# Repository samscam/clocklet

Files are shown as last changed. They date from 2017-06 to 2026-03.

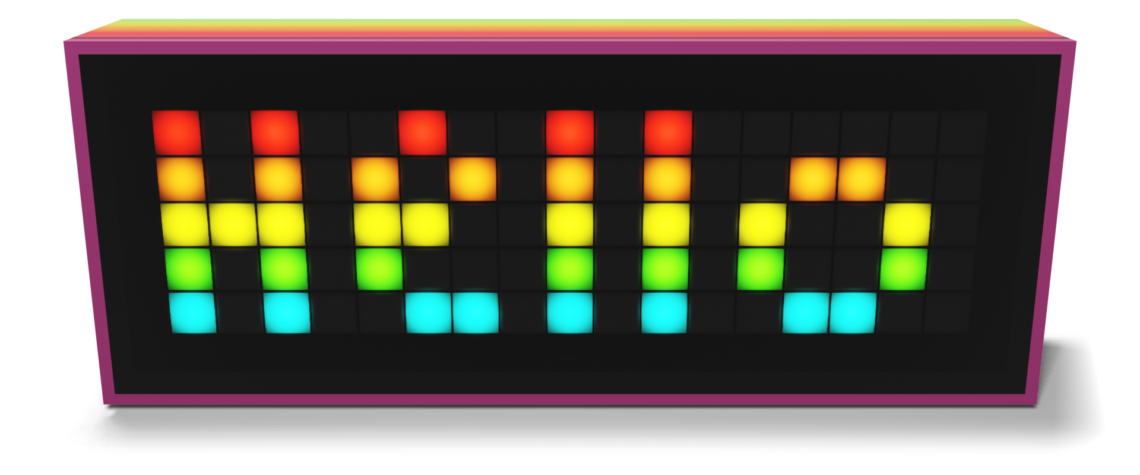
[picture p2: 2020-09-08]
Website/images/clocklet5-tequillasunrise.png

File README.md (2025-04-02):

# Clocklet

See also [clocklet.co.uk](https://clocklet.co.uk)

## Overview

This project is the firmware and client apps for clocks made by @samscam including:

### Clocklet
* Custom 17x5 SK9822 LED Matrix display
* Timekeeping: ESP32 (DS3231 as backup)
* Synchronisation: NTP
* Microcontroller: ESP32 Wrover on custom "Clockbrain" board
* Weather source: OpenWeatherMap

### Old Clocklet / Clocky
Earlier prototypes used RGBDigit (WS2812B) 7-segment display and Adafruit Feather Huzzah32.

### Mrs Clockety
* Display: Waveshare epaper 2.9inch https://www.waveshare.com/2.9inch-e-paper-module.htm
* Timekeeping: GPS
* Synchronisation: GPS
* Power management to run from a lipo battery
* Microcontroller: Adafruit Feather Huzzah32

It's all a work in progress.

## Main Features

* Time
* Weather
* Utterances
* Interesing displays and animation
* Ambient light sensing
* Power management (Mrs Clockety)

## Firmware

To build the the firmware:

* Clone the repo **including submodules**
* Install platformio and your editor of choice - I'm using vscode.
* Open up the firmware from the `Embedded` directory
* Pick the *correct environment* for the device you want to build for (by setting it in the first line of `platformio.ini` or by invoking tasks for the specific environment in the editor/cli) this will probably be `clockbrain`
* Plug the device in to your machine over USB
* Check that the device is available to your system... on MacOS it's normally `/dev/cu.SLAB_USBtoUART`
* Build and upload (platformio should download the dependencies if it hasn't done so already)
* Note that API keys are encrypted with gitcrypt

## Seeing the logs (without installing anything much)

You can connect to the clocklet's serial port from a computer with various tools (like screen, miniterm or putty) and see the Clocklet logging.

The important thing to note is that the baud rate of the serial connection is `115200`.

The Clocklet serial port on Mac and Linux will be available as something like `/dev/cu.SLAB_USBtoUART` - you can do an `ls /dev/cu.*` before and after plugging it in to eliminate possibilities.

Then open it up in your tool of choice:
`screen /dev/cu.SLAB_USBtoUART 115200`
`miniterm.py /dev/cu.SLAB_USBtoUART 115200`

## Manually updating firmware (with minimal installing)

1) Install `esptool`

On MacOS this can be done with homebrew: `brew install esptool`
On Linuxes it's probably available from `apt install esptool` or whatever package manager you're using.

2) Download the bin file of the firmware image you want from the releases section on here.

3) Plug in the Clocklet and figure out which port it is on - probably something like `/dev/cu.SLAB_USBtoUART` (that's what we'll use here but replace with whatever it is on your system)

4) Erase the flash (including settings)
`esptool.py -b 115200 -p /dev/cu.SLAB_USBtoUART erase_region 0x9000 0xFF7000`

5) Flash the new firmware image:

`esptool.py -b 115200 -p /dev/cu.SLAB_USBtoUART write_flash 0x10000 clockbrain.bin`

While we are here you can also use esptool to just erase settings (equivalent of doing a factory reset from the app): 
`esptool.py -b 115200 -p /dev/cu.SLAB_USBtoUART erase_region 0x9000 0x5000`

## Client App (iOS)

*Requires Xcode 16*
To build, open via the workspace rather than the Xcode Project.

Contains an experimental library for gluing CoreBluetooth to Combine and SwiftUI via PropertyWrappers called "CombineBluetooth". This may get spun out into a separate project in the future - but for ease of development right now it's in here.

## To follow

* Android client
* Enclosure design (3d printable)
* Hardware design

## License

This is distributed under the MIT License

    MIT License

    Copyright (c) 2017-2020 Sam Easterby-Smith

    Permission is hereby granted, free of charge, to any person obtaining a copy
    of this software and associated documentation files (the "Software"), to deal
    in the Software without restriction, including without limitation the rights
    to use, copy, modify, merge, publish, distribute, sublicense, and/or sell
    copies of the Software, and to permit persons to whom the Software is
    furnished to do so, subject to the following conditions:

    The above copyright notice and this permission notice shall be included in all
    copies or substantial portions of the Software.

    THE SOFTWARE IS PROVIDED "AS IS", WITHOUT WARRANTY OF ANY KIND, EXPRESS OR
    IMPLIED, INCLUDING BUT NOT LIMITED TO THE WARRANTIES OF MERCHANTABILITY,
    FITNESS FOR A PARTICULAR PURPOSE AND NONINFRINGEMENT. IN NO EVENT SHALL THE
    AUTHORS OR COPYRIGHT HOLDERS BE LIABLE FOR ANY CLAIM, DAMAGES OR OTHER
    LIABILITY, WHETHER IN AN ACTION OF CONTRACT, TORT OR OTHERWISE, ARISING FROM,
    OUT OF OR IN CONNECTION WITH THE SOFTWARE OR THE USE OR OTHER DEALINGS IN THE
    SOFTWARE.

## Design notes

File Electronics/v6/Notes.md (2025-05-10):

# V6 design notes

## USB-C Socket

On the v5 I had a sticky-out socket (in the middle of the board)
For this one do we want to carry on with that, and have it exit at the rear, (standing paste) or come out at the side (horizontal attach, which would be simpler??)

There are bazillions in the JLC catalogue but we are talking
- 16 pin
- good enough rating for current (need to work out hypothetical max limit)

## ESD protection

Doing this right is more complex than I had thought.

We need over-voltage protection and ESD protection.
on Vbus
CC lines
D+/- lines

Options: 

### The semtech way:
https://www.semtech.com/uploads/design-support/TVS_App_Notes-SI21-03-ESD_Protection_of_USB_Type-C_Interfaces.pdf

Semtech TDS2221PW for vBUS
µClamp2411ZA for CC
RClamp4021ZA for D+/-

Or they do this thing
https://estore.st.com/en/tcpp01-m12-cpn.html

### The TI way:
https://www.ti.com/lit/ta/ssztal6/ssztal6.pdf

TPD6S300
does 6 channels CC, SBU, D+/-
or TPD8S300 for 8 channels
Still need something for vbus
https://www.ti.com/lit/ds/slvsdk3c/slvsdk3c.pdf?ts=1744796360041

TPD4S480
4 channels, newer, 48v compliant
https://www.ti.com/lit/ds/symlink/tpd4s480.pdf

ESD122 - if we wanted to do the high speed lines (but we don't)
https://www.ti.com/lit/ds/symlink/esd122.pdf

## USB-PD controller

TPS25730
https://www.ti.com/lit/ds/symlink/tps25730.pdf

Has a 3v3 LDO built in for output BUT that's limited to 0.1A

TPS25751 has built in esd protection... and moisure detection
https://www.ti.com/lit/ds/symlink/tps25751.pdf

TPS26750 doesn't have esd - says you should pair with TPD4S480
https://www.ti.com/product/TPS26750

## LDO

These both coming off the PPHV line of the PD controller...

3.3v
then we need an LDO for the 3v3 supply for the MCU
old one was AP2112K-3.3
JLC have AMS1117 (which is rated for 1A)

5v
Presuming that we are sticking with 5v LEDs...

Possibly a buck?

Or is there a dual channel power regulator thing? One for 5v and one for 3.3v?

## MUX

It's probably unnecessary but we could put a mux on the D+- lines. Or just join them together.

## MCU

Espressiv ESP32-S3
https://www.espressif.com/sites/default/files/documentation/esp32-s3_datasheet_en.pdf

Sensible plan is to use the "mini" one with built-in antenna.
Which does have placement implications.
It's that or go there with doing RF and have an antenna somewhere.
Current rating recommendation 500mA.

## LEDs

current - 5*17 matrix = 85 LEDs

Currently using SK9822
http://www.normandled.com/upload/201909/SK9822%20LED%20Datasheet.pdf
Those are max 20ma each = 1.7A

Which puts our total max power budget at roughly 2.4A * 5V = 12W
(but we never actually go that high, probably)

As we are getting PCBA this time... Possibly do 2020 ones?

2020s seem to work out more like 18ma

HD107
HD108 - 16bit - 20ma in the 5050 package
https://www.rose-lighting.com/wp-content/uploads/sites/53/2019/11/HD108-led.pdf
(rose lighting datasheets are a mess)

WS2816 (recently supported in fastled) - is a 1-wire thing but 16-bit.
Better availability... but not sure I like it and would prefer the APA102 style spi interface.
SK9822 are readily available.

BIG QUESTION:
Single board with everything on one side.
Double sided.
Sandwich

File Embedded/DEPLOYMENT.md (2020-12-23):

# Clocklet deployment procedure

1) Plug in, then insert battery
2) Burn efuses (including serial number)
3) Apply profile to CP2012N (with Simplicity Studio)
4) Flash the firmware
5) Get the time set in the DS3231
6) Erase to defaults

## Clockbrain efuse map

EFUSE block 3:
0        1        2        3        4        5        6        7        << words
0        4        8        12       16       20       24       28       << bytes
0        32       64       96       128      160      192      224      << bits
00000000 00000000 00000000 00000000 00000000 00000000 00000000 00000000 << hex
reserved xxxx                                         ^ hw     ^ serial

So that's block 6 for the hardware revision (uint16) and case colour (uint16)
And block 7 for the serial number (uint32)

## Writing the efuse

Adjust the serial number in the `efuse.bin` file - remember it's LITTLE ENDIAN.

hwrev    serial
V        V
05000300 08000000
    ^
    case colour

And burn it!

~/.platformio/packages/tool-esptoolpy/espefuse.py --port /dev/tty.usbserial-114440 burn_block_data --offset 24 BLK3 efuse.bin

(use --force-write-always if necessary)

Case colours
00 (unset) raw hardware
01 fake wood
02 translucent
03 rainbow blue-pink
04 white
05 galaxy black
06 gold
07 tequilla sunrise

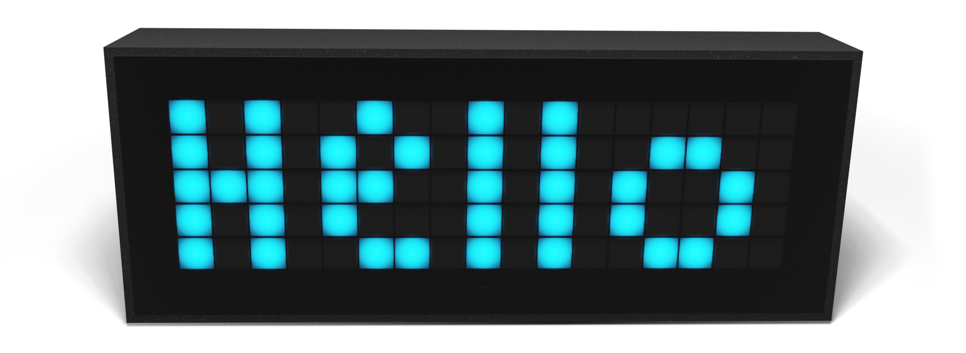
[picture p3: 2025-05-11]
Website/images/clocklet5-blue-hello.png

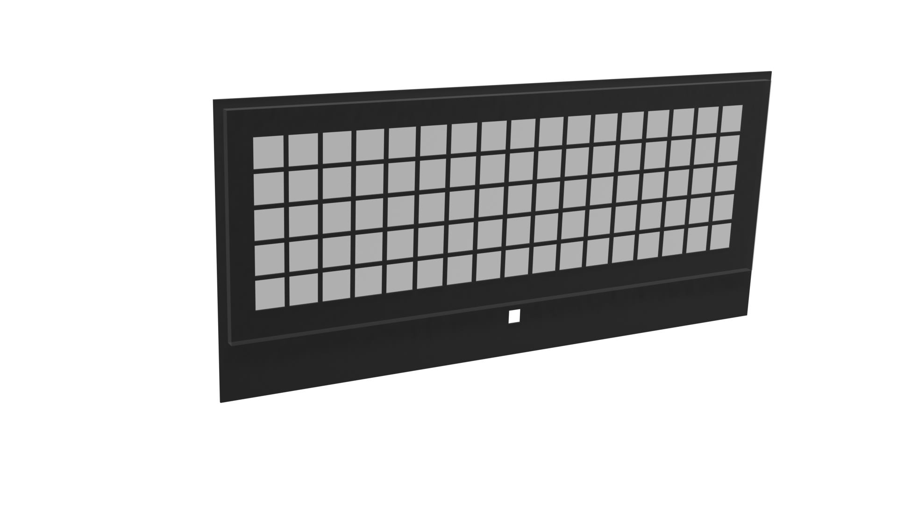
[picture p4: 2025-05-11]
Website/images/clocklet5-black-mask.png

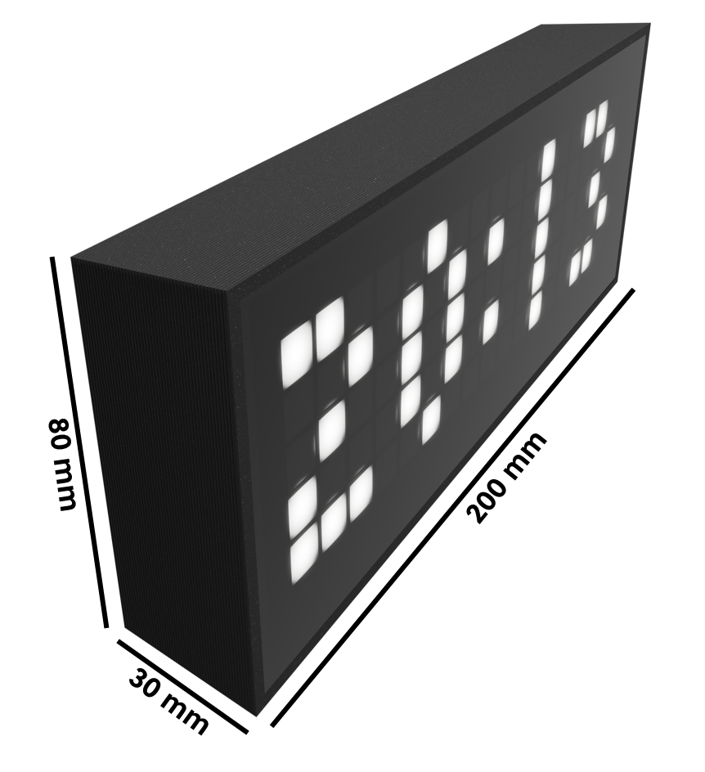
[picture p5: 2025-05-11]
Website/images/dimensions.png

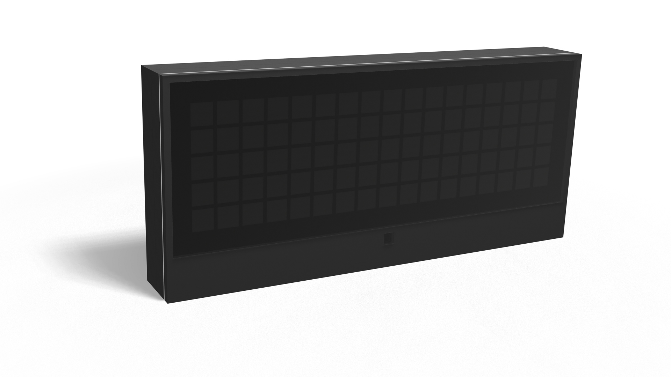
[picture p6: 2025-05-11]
Website/images/clocklet5-black-blank.png

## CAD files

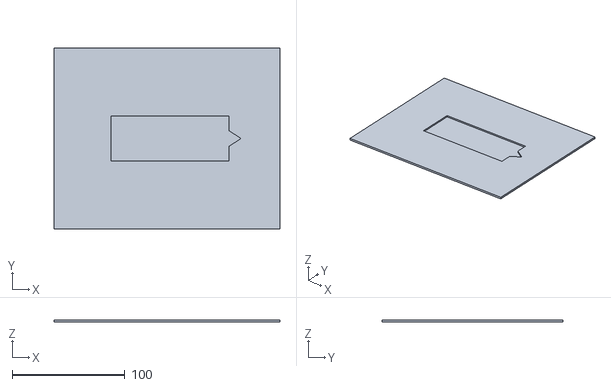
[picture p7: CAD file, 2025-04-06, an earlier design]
Electronics/v5/Display-2020/stencil holder.stl
200.0 x 160.0 x 2.00

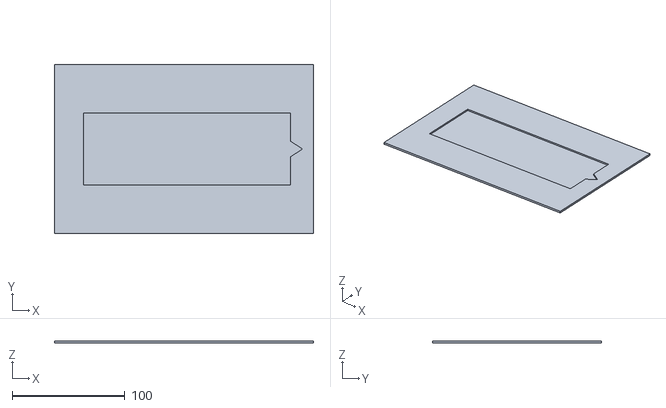
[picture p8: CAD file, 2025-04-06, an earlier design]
Electronics/v5/Display-APA/stencil holder.stl
230.0 x 150.0 x 2.00

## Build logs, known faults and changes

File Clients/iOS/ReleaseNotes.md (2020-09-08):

# Clocklet iOS Release notes

## v1.0 (92)

This goes with Clocklet firmware v1.0.1

### NEW USERS HELLO!

Plug in your clock, run the app, set up network and location. Happy clock!

### NEW STUFF IN THIS VERSION

* Changing locations
You can now change the location of the Clocklet on the new location settings screen. There are some canned examples or you can set it to your real location. Changing location will also trigger a weather update - though if you change locations repeatedly you will likely end up with the weather for a previous place.

* International time zone and DST support
The clock's time should reflect the time in the chosen location. Even for places with crazy timezones.

* Bluetooth status improvements
On your phone, if bluetooth is switched off or not authorised you should see a helpful overlay telling you to do something about it.
The app will now correctly report when pairing data is messed up - you can (if you really want to) test this by performing a factory reset on the clock and then trying to reconnect. To clear the error, remove the clocklet from your phone's bluetooth settings and try connecting again. No need to kill the app.

* Various layout improvements in the app
* Fixed occasional jerkyness on the Clocklet's display (by running network tasks on the other core)

### MIGRATIONS FROM EARLIER VERSIONS

After installing the app, check your Clocklet's firmware version is v1.0.1 in the technical stuff section. Rebooting will trigger an update if it hasn't already done it.

Background or quit the app while the clock is doing the firmware update - otherwise the update will fail.

After performing a firmware update, or otherwise if settings are missing/messed up in the app, you should switch bluetooth on your phone off and on again to clear the bluetooth cache.

After migrating, your phone will report the Clock's location as "Nowhere" - just change the location to sort it out.

### ANNOYING BUGS

I've had a few times where the Clocklet fails to advertise itself properly, thus either not showing up in the app or looking like a circuit board. Turning the clock off and on again should fix it.

Have seen some occasional crashes on the clocklet (shortly after startup or after multiple location changes) but they also seem to sort themselves out. Will carry on trying to track them down.

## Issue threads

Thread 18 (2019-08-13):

NTP goes into loop when starting with a fresh DS3231

samscam, 2019-08-13:
The daily updates fire continuously - presumably the initial time hasn't stuck.
Or something... It started working in the end. Investigate...

samscam, 2020-05-15:
This is all down to known behaviour with a fresh DS3231 - Apply power to 3v3 before inserting battery.

Closed 2020-05-15.

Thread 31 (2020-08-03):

Firmware Updates fail if also trying to do other network stuff (like scanning because bluetooth is connected)

samscam, 2020-08-03:

samscam, 2020-09-08:
This has been fixed by having switched over to Nimble. Closing.

Closed 2020-09-08.

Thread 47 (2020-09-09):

iOS start Bluetooth search AFTER Bluetooth perm has been granted

samscam, 2020-09-09:
When you give bluetooth permission on the first run it has already tried to scan, and has probably failed. Users need to manually tap the scan button. Not good enough!

Closed 2022-12-30.

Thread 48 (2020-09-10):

Bob's network joining problems

samscam, 2020-09-10:
Bob is struggling to get it to connect to his network.

Possible causes:
Watchdog timer - likely network scan task stuck in a loop
Mutex locks relating to system time - main clock process vs nimble
WEP
Network characteristic over-subscribing to network events

samscam, 2020-09-12:
Another possible cause might be hidden SSIDs

samscam, 2020-09-12:
We can safely discount WEP. Did a bunch of tests on it and it was fine.

samscam, 2022-12-09:
Closing this as I presume it's fine now.

Closed 2022-12-09.

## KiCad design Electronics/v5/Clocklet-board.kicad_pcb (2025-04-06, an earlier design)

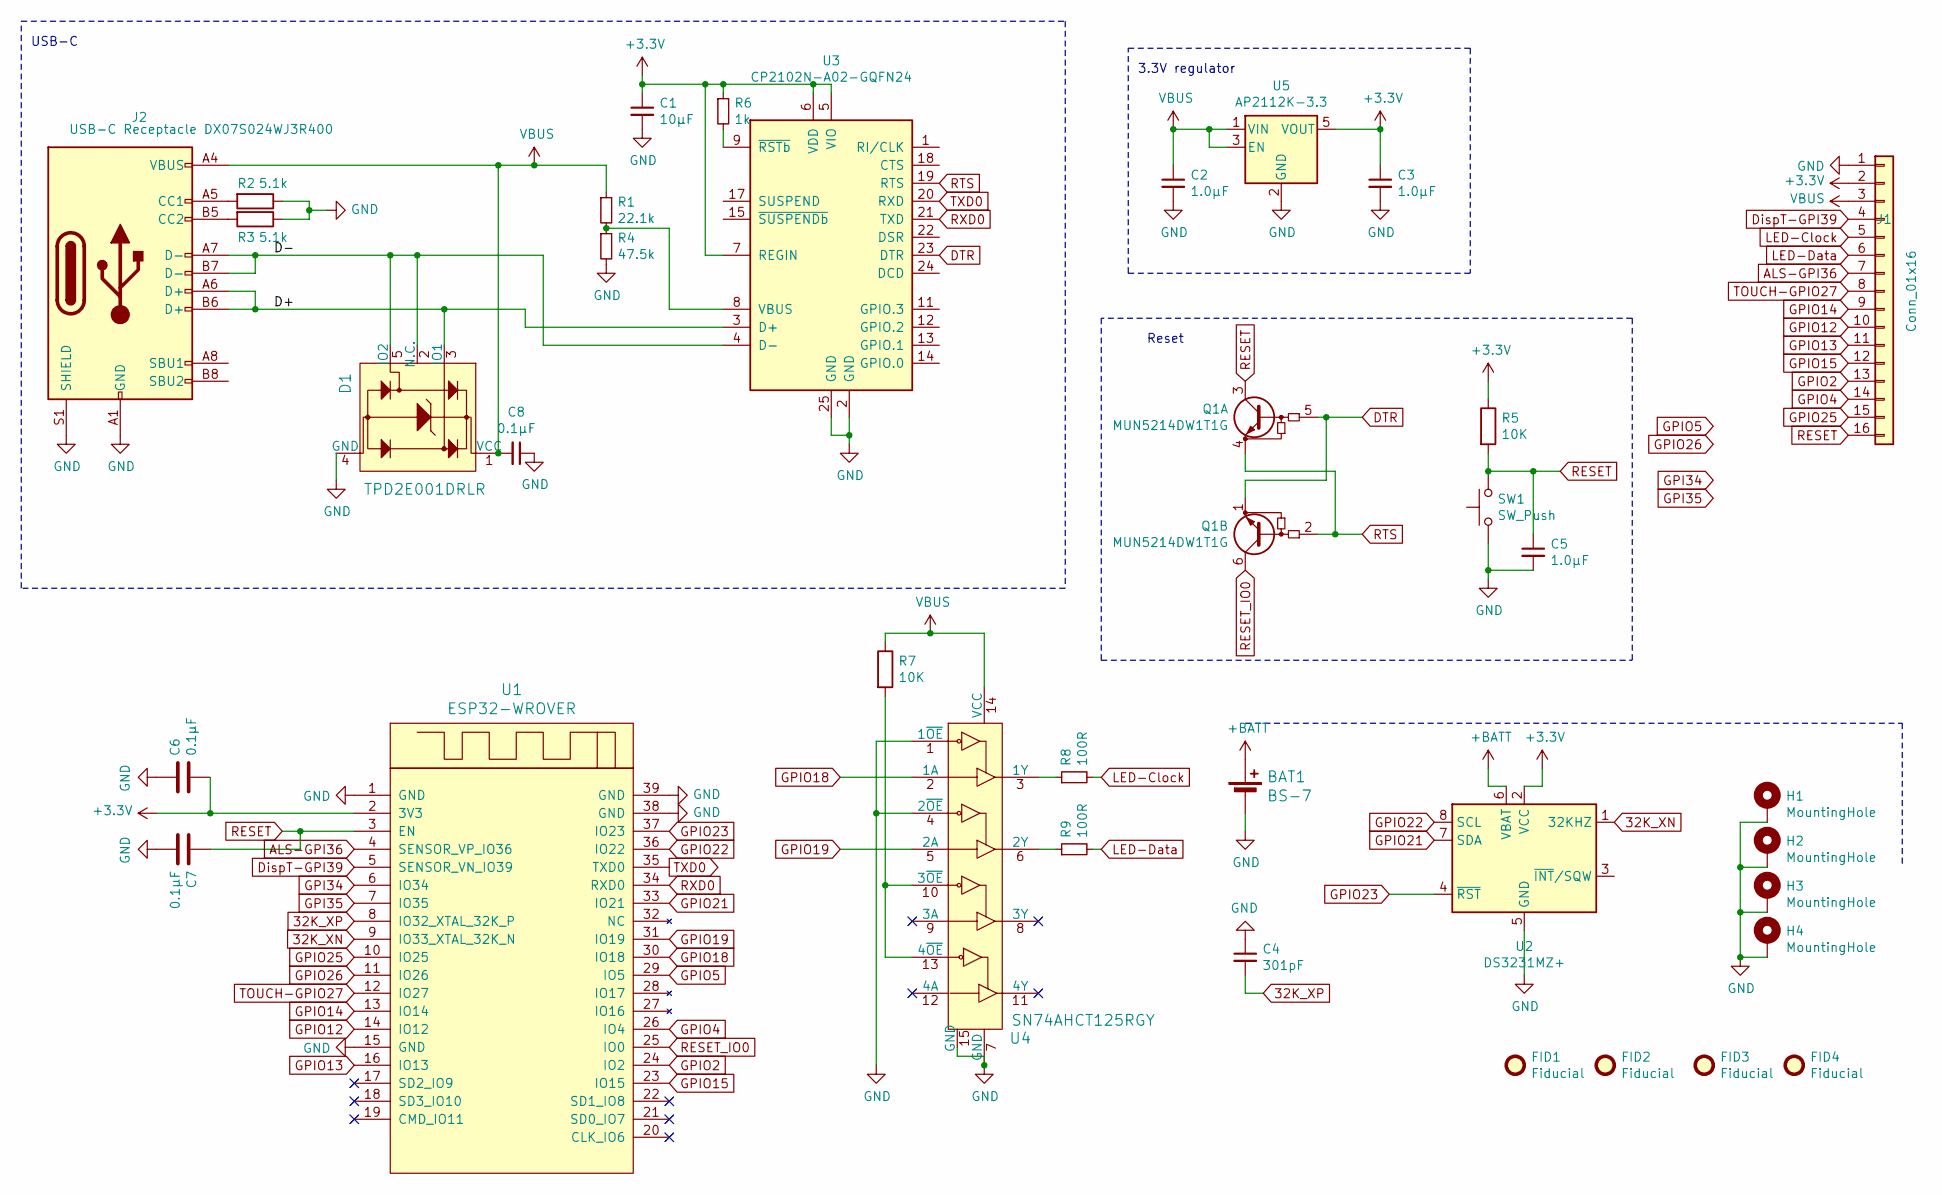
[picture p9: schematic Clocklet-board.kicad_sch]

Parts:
BAT1: BS-7; BatteryHolder_Keystone_3000_1x12mm; MPN BS-7; Digi-Key_PN BS-7-ND
C1: 10µF; C_0603_1608Metric; Mouser Ref 80-C0603C106M8PACTU
C2, C3, C5: 1.0µF; C_0603_1608Metric; Mouser Ref 80-C0603C105K4PLR
C4: 301pF; C_0603_1608Metric; Mouser Ref 80-C0603C301J8HACTU
C6, C7, C8: 0.1µF; C_0603_1608Metric; Mouser Ref 710-885012206071
D1: TPD2E001DRLR; SOT-553; MPN TPD2E001DRLR; Digi-Key_PN 296-21883-1-ND
FID1, FID2, FID3, FID4: Fiducial; Fiducial_0.5mm_Mask1mm
H1: MountingHole; MountingHole_2.7mm_M2.5_Pad_Via
H2, H3, H4: MountingHole; MountingHole_2.5mm_Pad_Via
J1: Conn_01x16; PinHeader_1x16_P2.54mm_Vertical
J2: USB-C Receptacle DX07S024WJ3R400; USB-C_Female_Vert_DX07S024WJ3R400-Corrected; Mouser Ref 656-DX07S0024WJ3R400
Q1: MUN5214DW1T1G; SOT-363_SC-70-6; Mouser Ref 863-MUN5214DW1T1G
R1: 22.1k; R_0603_1608Metric; Mouser Ref 71-CRCW060322K1FKEAC
R2, R3: 5.1k; R_0603_1608Metric; Mouser Ref 71-CRCW06035K10FKEAC
R4: 47.5k; R_0603_1608Metric; Mouser Ref 71-CRCW060347K5FKEAC
R5, R7: 10K; R_0603_1608Metric; Mouser Ref 71-CRCW060310K0FKEAC
R6: 1k; R_0603_1608Metric; Mouser Ref 71-CRCW06031K00FKEAC
R8, R9: 100R; R_0603_1608Metric; Mouser Ref 71-CRCW0603100RFKEAC
SW1: SW_Push; SW_SPST_B3U-1000P; Mouser Ref 653-B3U-1000P
U1: ESP32-WROVER; ESP32-WROVER-B-Recs; Mouser Ref 356-ESP32-WROB(16MB)
U2: DS3231MZ+; SOIC-8_3.9x4.9mm_P1.27mm; Mouser Ref 700-DS3231MZ+
U3: CP2102N-A02-GQFN24; QFN-24-1EP_4x4mm_P0.5mm_EP2.6x2.6mm_ThermalVias; Mouser Ref 634-CP2102NA02GQFN24
U4: SN74AHCT125RGY; Texas_S-PVQFN-N14_ThermalVias; MPN SN74AHCT125N; Digi-Key_PN 296-4655-5-ND
U5: AP2112K-3.3; SOT-23-5; Mouser Ref 621-AP2112K-3.3TRG1

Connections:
32K_XN: U1.9 (IO33_XTAL_32K_N), U2.1 (32KHZ)
32K_XP: C4.2, U1.8 (IO32_XTAL_32K_P)
+3V3: C1.1, C3.1, C6.2, J1.2, R5.1, R6.1, U1.2 (3V3), U2.2 (VCC), U3.5 (VIO), U3.6 (VDD), U3.7 (REGIN), U5.5 (VOUT)
+BATT: BAT1.1 (+), U2.6 (VBAT)
/D+: D1.3 (IO1), J2.A6 (D+), J2.B6 (D+), U3.3 (D+)
/D-: D1.2 (N.C.), D1.5 (IO2), J2.A7 (D-), J2.B7 (D-), U3.4 (D-)
ALS-GPI36: J1.7, U1.4 (SENSOR_VP_IO36)
DTR: Q1.1 (E1), Q1.5 (B1), U3.23 (DTR)
DispT-GPI39: J1.4, U1.5 (SENSOR_VN_IO39)
GND: BAT1.2 (-), C1.2, C2.2, C3.2, C4.1, C5.2, C6.1, C7.2, C8.1, D1.4 (GND), H1.1, H2.1, H3.1, H4.1, J1.1, J2.A1 (GND), J2.A12 (GND), J2.B1 (GND), J2.B12 (GND), J2.S1 (SHIELD), R2.1, R3.1, R4.2, SW1.1, U1.1 (GND), U1.15 (GND), U1.38 (GND), U1.39 (GND), U2.5 (GND), U3.2 (GND), U3.25 (GND), U4.1 (1~OE), U4.4 (2~OE), U4.7 (GND), U4.15 (GND), U5.2 (GND)
GPI34: U1.6 (IO34)
GPI35: U1.7 (IO35)
GPIO2: J1.13, U1.24 (IO2)
GPIO4: J1.14, U1.26 (IO4)
GPIO5: U1.29 (IO5)
GPIO12: J1.10, U1.14 (IO12)
GPIO13: J1.11, U1.16 (IO13)
GPIO14: J1.9, U1.13 (IO14)
GPIO15: J1.12, U1.23 (IO15)
GPIO18: U1.30 (IO18), U4.2 (1A)
GPIO19: U1.31 (IO19), U4.5 (2A)
GPIO21: U1.33 (IO21), U2.7 (SDA)
GPIO22: U1.36 (IO22), U2.8 (SCL)
GPIO23: U1.37 (IO23), U2.4 (~RST)
GPIO25: J1.15, U1.10 (IO25)
GPIO26: U1.11 (IO26)
LED-Clock: J1.5, R8.2
LED-Data: J1.6, R9.2
unnamed: J2.A5 (CC1), R2.2
unnamed: J2.B5 (CC2), R3.2
unnamed: R1.2, R4.1, U3.8 (VBUS)
unnamed: R6.2, U3.9 (~RSTb)
unnamed: R7.2, U4.10 (3~OE), U4.13 (4~OE)
unnamed: R8.1, U4.3 (1Y)
unnamed: R9.1, U4.6 (2Y)
RESET: C5.1, C7.1, J1.16, Q1.3 (C1), R5.2, SW1.2, U1.3 (EN)
RESET_IO0: Q1.6 (C1), U1.25 (IO0)
RTS: Q1.2 (B1), Q1.4 (E1), U3.19 (RTS)
RXD0: U1.34 (RXD0), U3.21 (TXD)
TOUCH-GPIO27: J1.8, U1.12 (IO27)
TXD0: U1.35 (TXD0), U3.20 (RXD)
VBUS: C2.1, C8.2, D1.1 (VCC), J1.3, J2.A4 (VBUS), J2.A9 (VBUS), J2.B4 (VBUS), J2.B9 (VBUS), R1.1, R7.1, U4.14 (VCC), U5.1 (VIN), U5.3 (EN)

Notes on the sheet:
3.3V regulator
Reset
USB-C

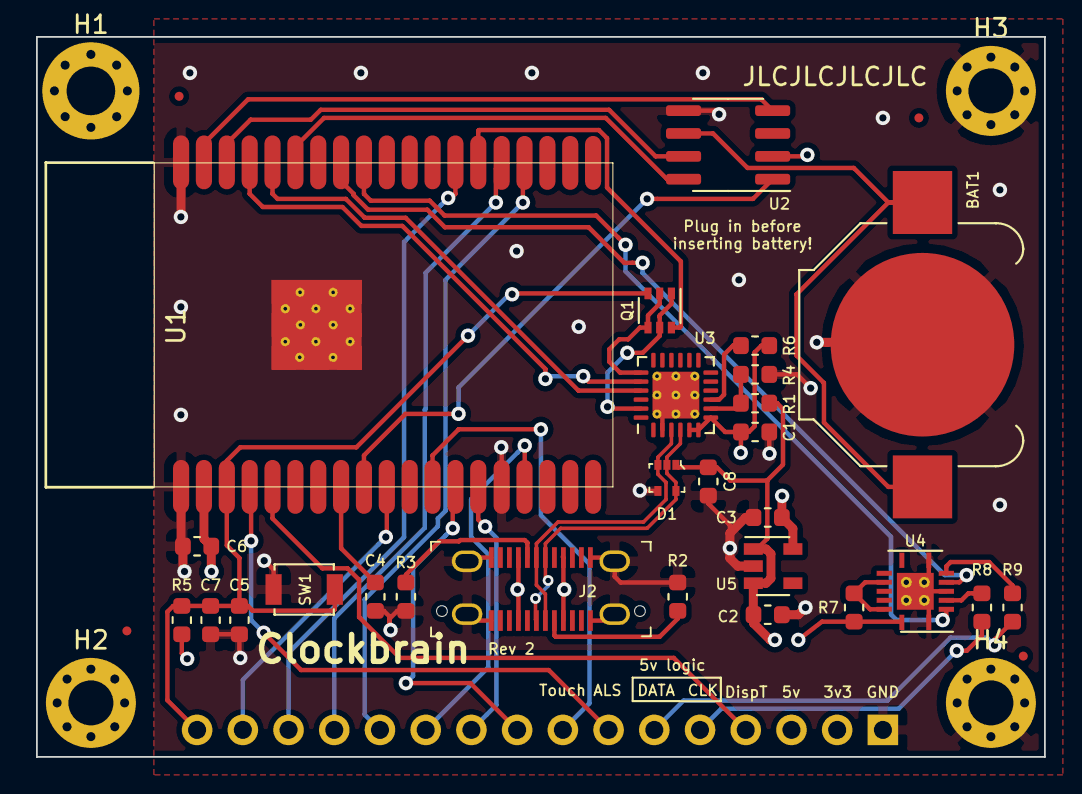
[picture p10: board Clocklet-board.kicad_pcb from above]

Board: 4 copper layers, 56.0 x 40.0 mm, 36 parts (1 on the bottom side), 38 nets.

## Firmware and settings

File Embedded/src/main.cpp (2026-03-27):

#include "main.h"

#include "Tests/Tests.h"
#include "settings.h"
#include "Messages.h"
#include "Displays/Display.h"
#include "Location/LocationSource.h"
#include "Location/LocationManager.h"
#include <WiFi.h>
#include <esp_log.h>

#include "Bluetooth/BlueStuff.h"

#include "FirmwareUpdates/FirmwareUpdates.h"
#include <Preferences.h>


#include "Loggery.h"

#include <rom/uart.h>
#include <soc/efuse_reg.h>

#include "TimeThings/TimeSync.h"

#include "ClockletSystem.h"

#define TAG "PRISCILLA"

// ----------- Display

#if defined(RAINBOWDISPLAY)

#include "Displays/RGBDigit.h"
RGBDigit display = RGBDigit();

#elif defined(MATRIX)

#include "Displays/Matrix/Matrix.h"
Matrix display = Matrix();

#elif defined(EPAPER)

#include "Displays/Epaper.h"
EpaperDisplay display = EpaperDisplay();

#endif


//Adafruit7 display = Adafruit7();

// #include "Displays/DebugDisplay.h"
// Display *display = new DebugDisplay();

// ----------- RTC

// We will always use the internal ESP32 time now...
#include "TimeThings/ESP32Rtc.h"
RTC_ESP32 rtc = RTC_ESP32();


#if defined(TIME_GPS)
#include "TimeThings/GPSTime.h"
RTC_GPS gpsRTC = RTC_GPS();
#endif

#if defined(TIME_DS3231)
RTC_DS3231 ds3231 = RTC_DS3231();
#endif

// TimeSync
TimeSync *timeSync;

// Location

#if defined(LOCATION_GPS)
LocationSource locationSource = rtc;
#else
LocationManager *locationManager;
#endif


// ---------- WEATHER CLIENT

// // #include "weather/met-office.h"
// // WeatherClient *weatherClient = new MetOffice(client); // << It's plain HTTP

// #include "weather/darksky.h"
// DarkSky weatherClient = DarkSky();

#include "weather/openweathermap.h"
OpenWeatherMap *weatherClient;

// RAINBOWS
#include "Weather/Rainbows.h"
Rainbows rainbows;

// Global Notification queues
QueueHandle_t bluetoothConnectedQueue;
QueueHandle_t prefsChangedQueue;
QueueHandle_t weatherChangedQueue;
QueueHandle_t locationChangedQueue;
QueueHandle_t networkChangedQueue;
QueueHandle_t networkStatusQueue;
QueueHandle_t firmwareUpdateQueue;
QueueHandle_t godModeQueue;

// God Mode
GodModeSettings godModeSettings;

// Firmware updater
FirmwareUpdates *firmwareUpdates;

// Update scheduler
UpdateScheduler updateScheduler = UpdateScheduler();

// Bluetooth implementation
BlueStuff *blueStuff;

// SETUP  --------------------------------------
void setup() {


  delay(2000);
  
  Serial.begin(115200);
  LOGMEM;
  // Say hello on Serial port
  Serial.println("");
  Serial.println("   ------------    ");
  Serial.println("  /            \\   ");
  Serial.println("  --------------   ");
  Serial.println(" |              |   ");
  Serial.println(" | ! CLOCKLET ! |   ");
  Serial.println(" |              |   ");
  Serial.println("  --------------   \n");

  Serial.printf("Firmware Version: %s (%s)\n",VERSION,GIT_HASH);

  // Read things from eFuse

  uint16_t hwrev = clocklet_hwrev();
  uint16_t caseColour = clocklet_caseColour();
  uint32_t serial = clocklet_serial();

  Serial.printf("Serial number: %d\n",serial);
  Serial.printf("Hardware revision: %d\n",hwrev);
  Serial.printf("Case Colour: %d\n",caseColour);

  // Read things from preferences...
  Preferences preferences = Preferences();
  preferences.begin("clocklet", false);

  // Post-update migrations
  String swmigrev = preferences.getString("swmigrev","0.0.0");

  if (swmigrev != VERSION){
    ESP_LOGI(TAG,"Previously running: %s\n",swmigrev.c_str());
    preferences.putString("swmigrev",VERSION);
    ESP_LOGI(TAG,"MIGRATED!");
  }

  preferences.end();

  LOGMEM;

  // Notification queues
  bluetoothConnectedQueue = xQueueCreate(1, sizeof(bool));
  prefsChangedQueue = xQueueCreate(1, sizeof(bool));
  weatherChangedQueue = xQueueCreate(1, sizeof(bool));
  locationChangedQueue = xQueueCreate(1, sizeof(bool));
  networkChangedQueue = xQueueCreate(1, sizeof(bool));
  networkStatusQueue =  xQueueCreate(1, sizeof(wl_status_t));
  firmwareUpdateQueue = xQueueCreate(1, sizeof(FirmwareUpdateStatus));
  godModeQueue = xQueueCreate(1, sizeof(GodModeSettings));

  // Analog input for light pin
  analogReadResolution(12);
  analogSetPinAttenuation(LIGHT_PIN,ADC_0db);

  // seed the brightness
  for (int i = 0; i<10 ; i++){
    currentBrightness();
    delay(100);
  }

  ESP_LOGI(TAG,"Clock starting!");


  display.setup();
  display.setBrightness(currentBrightness());


  // Uncomment to run various display tests:
  // displayTests(&display);  

  // DISPLAY A GREETING
  display.displayMessage("CLOCKLET",rainbow);

  updateDisplayPreferences();

  WiFi.begin();


  locationManager = new LocationManager(locationChangedQueue);
  ClockLocation currentLocation = locationManager->getLocation();

  blueStuff = new BlueStuff(bluetoothConnectedQueue,prefsChangedQueue,networkChangedQueue,networkStatusQueue,godModeQueue,locationManager);
  blueStuff->startBlueStuff();


  weatherClient = new OpenWeatherMap();
  weatherClient->weatherChangedQueue = weatherChangedQueue;
  weatherClient->setLocation(currentLocation);
  weatherClient->setTimeHorizon(12);
  updateScheduler.addJob(weatherClient,"weather",hourly);

  rainbows.setLocation(currentLocation);

  rtc.setTimeZone(currentLocation.timeZone);

  // Setup DS3231
  // Initialise I2c stuff (DS3231)
  #if defined(TIME_DS3231)

    #if defined(CLOCKBRAIN)
    Wire.begin(22, 21); // Got the damn pins the wrong way round on clockbrain
    #else
    Wire.begin();
    #endif

    if (!ds3231.begin()){
      ESP_LOGE(TAG,"Could not connect to DS3231");
    }

    timeSync = new TimeSync(&ds3231, &rtc); // << deliberately leaking these here - should really go smart pointers
    timeSync->performUpdate();
    updateScheduler.addJob(timeSync,"timesync",hourly);
    
  #endif




  // Start the internal RTC and NTP sync
  rtc.begin();

  // Firmware updatedr
  firmwareUpdates = new FirmwareUpdates(firmwareUpdateQueue);
  updateScheduler.addJob(firmwareUpdates,"firmware",daily);

  // Start Update Scheduler
  updateScheduler.start();

}

// LOOP  --------------------------------------


unsigned long lastRandomMessageTime = millis();
unsigned long nextMessageDelay = 1000 * 60 * 2;

unsigned long lastHourlyUpdate = 0;
unsigned long lastDailyUpdate = 0;


enum Precision {
  minutes, seconds, subseconds
};

Precision precision = subseconds;
// #if defined(RAINBOWDISPLAY)
// Precision precision = subseconds;
// #else
// Precision precision = minutes;
// #endif

bool didDisplay = false;

FirmwareUpdateStatus fwUpdateStatus = idle;
bool fwUpdateStarted = false;
bool bluetoothConnected = false;

float_t brightnessAdjust = 1;
bool autoBrightness = true;

void loop() {

  
  // ---- MONITOR QUEUES -----

  // ... preferences
  bool prefsDidChange = false;
  xQueueReceive(prefsChangedQueue, &prefsDidChange, (TickType_t)0 );
  if (prefsDidChange){
    ESP_LOGD(TAG,"PREFS DID CHANGE");
    updateDisplayPreferences();
  }
  
  display.setBrightness(currentBrightness());

  // ... weather
  bool weatherDidChange = false;
  xQueueReceive(weatherChangedQueue, &weatherDidChange, (TickType_t)0 );
  if (weatherDidChange && !godModeSettings.enabled){
    ESP_LOGI(TAG,"Weather did change");
    display.setWeather(weatherClient->horizonWeather);
    rainbows.setWeather(weatherClient->rainbowWeather);
  }

  // ... location
  bool locationDidChange = false;
  xQueueReceive(locationChangedQueue, &locationDidChange, (TickType_t)0 );
  if (locationDidChange){
    ESP_LOGI(TAG,"Location did change");
    ClockLocation location = locationManager->getLocation();
    weatherClient->setLocation(location);
    rainbows.setLocation(location);
    rtc.setTimeZone(location.timeZone);
  }

  // Bluetooth Connected
  bool bluetoothDidConnect = false;
  if (xQueueReceive(bluetoothConnectedQueue, &bluetoothDidConnect, (TickType_t)0 )){
    bluetoothConnected = bluetoothDidConnect;
    display.setDeviceState(bluetoothDidConnect ? bluetooth : ok);
  }

  // ... firmware updates
  
  xQueueReceive(firmwareUpdateQueue, &fwUpdateStatus, (TickType_t)0 );

  switch (fwUpdateStatus) {
    case idle:
      break;
    case updating:
      blueStuff->stopBlueStuff();
      if (!fwUpdateStarted){
        display.displayMessage("Updating Firmware", rando);
        fwUpdateStarted = true;
      } else {
        display.setStatusMessage("WAIT");
      }
      
      delay(100);
      return;

      break;
    case failed:
      blueStuff->startBlueStuff();
      display.displayMessage("Update failed... sorry :(",bad);
      fwUpdateStatus = idle;
      break;
    case complete:
      display.displayMessage("Update complete! Restarting...", good);
      ESP.restart();
      break;
  }

  // ... God Mode

  if (xQueueReceive(godModeQueue, &godModeSettings, (TickType_t)0 )){
    if (godModeSettings.enabled){
      display.setWeather(godModeSettings.weather);
    } else {
      display.setWeather(weatherClient->horizonWeather);
      rainbows.setWeather(weatherClient->rainbowWeather);
    }
  }
  


  // TOUCH SENSOR (Doesn't work)

  #if defined(TOUCH_SENSOR)
  // Check for touches... (This doesn't work on the clockbrain ... but it doesn't need to work!)
  long touchPeriod = detectTouchPeriod();
  if ( touchPeriod > 500 && touchPeriod < 10000){
    display.displayMessage("That tickles",rando);
  }
  touchPeriod = detectTouchPeriod();
  if (touchPeriod > 10000 && touchPeriod < 15000){
    display.displayMessage("Keep holding for restart",bad);
  }
  touchPeriod = detectTouchPeriod();
  if (touchPeriod > 15000){
    ESP.restart();
  }
  #endif

  // BATTERY MONITORING
  #if defined(BATTERY_MONITORING)
      float voltage = batteryVoltage();
      display.setBatteryLevel(batteryLevel(voltage));

      if (voltage < cutoffVoltage){
        
        espShutdown();
      }
  #endif

  #if defined(TIME_GPS)
    rtc.loop(); //<< needed on the GPS rtc to wake it :/
  #endif

  if (!bluetoothConnected){
    if (millis() > lastRandomMessageTime + nextMessageDelay){
      
      const char *message = randoMessage();
      ESP_LOGD(TAG,"Random message %s",message);
      display.displayMessage(message, rainbow);
      display.displayMessage(message, rainbow);

      lastRandomMessageTime = millis();
      nextMessageDelay = 1000 * 60 * random(5,59);
    }
  }


  DateTime time = rtc.now();
  DateTime localTime = rtc.localTime();
  double decimalTime = rtc.decimalTime();
  display.setRainbows(rainbows.rainbowProbability(time));
  display.setTime(localTime);
  display.setDecimalTime(decimalTime);
  display.frameLoop();

  sensibleDelay(1000/FPS);

  
}

void updateDisplayPreferences(){
  Preferences preferences = Preferences();
  preferences.begin("clocklet", false);
  
  String timeStyleString = preferences.getString("time_style");
  ESP_LOGD(TAG,"NEW TIME STYLE***** %s",timeStyleString);
  if (timeStyleString == "24 Hour"){
    display.setTimeStyle(twentyFourHour);
  } else if (timeStyleString == "12 Hour"){
    display.setTimeStyle(twelveHour);
  } else if (timeStyleString == "Decimal"){
    display.setTimeStyle(decimal);
  }

  brightnessAdjust = preferences.getFloat("brightness",0.5f);
  autoBrightness = preferences.getBool("autoBrightness",true);

  preferences.end();
}

void sensibleDelay(int milliseconds){
  #if defined(FastLED)// or fastled
    FastLED.delay(milliseconds);
  #else
    vTaskDelay(milliseconds / portTICK_PERIOD_MS);
  #endif // what if we don't
}


// MARK: BRIGHTNESS SENSING -------------------------

const int readingWindow = 10;
uint16_t readings[readingWindow] = {1024};
int readingIndex = 0;

float currentBrightness(){
  if (!autoBrightness){
    return brightnessAdjust;
  }

  readings[readingIndex] = analogRead(LIGHT_PIN);
  readingIndex++;
  if (readingIndex == readingWindow) { readingIndex = 0; }
  uint16_t sum = 0; // The sum can be a 16 bit integer because
  // 4096 goes into 2^16 - 16 times and we are doing 10 readings
  for (int loop = 0 ; loop < readingWindow; loop++) {
    sum += readings[loop];
  }

  float lightReading = sum / (float)readingWindow;

  lightReading = lightReading / 4096.0f;
  #if defined(CLOCKBRAIN) // actually this should be the display type
  lightReading = lightReading * 10.0f; // Boost the level somewhat
  #endif

  lightReading = (lightReading + (brightnessAdjust / 3)) * (brightnessAdjust * 2);
  
  lightReading = lightReading > 1.0f ? 1.0f : lightReading;

  return lightReading;

}

// MARK: TOUCH SENSITIVITY ------------------------
long startTouchMillis = 0;
uint16_t touchThreshold = 43;

/// Returns the number of ms which the user has been touching the device
long detectTouchPeriod(){
  int touchValue = touchRead(TOUCH_PIN);


  if (touchValue < touchThreshold){ // touch threshold is a mess
    if (!startTouchMillis){
      startTouchMillis = millis();
    }
    return millis() - startTouchMillis;
  } else {
    startTouchMillis = 0;
    return 0;
  }

}

// MARK: POWER MANAGEMENT -------------------------
// This stuff is for the one battery powered device I've built - mostly irrelevant at the moment

#if defined(BATTERY_MONITORING)

float batteryLevel(float voltage){
  float v = (voltage - cutoffVoltage) / (maxVoltage - cutoffVoltage);
  v = fmax(0.0f,v); // make sure it doesn't go negative
  return fmin(1.0f, v); // cap the level at 1
}

float batteryVoltage(){
  float reading = analogRead(BATTERY_PIN);
  return (reading / 4095.0f) * 2.0f * 3.3f * 1.1;
}

#endif


#if defined(ESP32)
void espSleep(int milliseconds){
  
  stopWifi();

  #if defined(TIME_GPS)
  rtc.sleep();
  #endif
  uart_tx_wait_idle(0);
  uint64_t microseconds = milliseconds * 1000;

  esp_err_t err = esp_sleep_enable_timer_wakeup( microseconds );
  if (err == ESP_ERR_INVALID_ARG){
    ESP_LOGE(TAG,"Sleep timer wakeup invalid");
    return;
  }
  err = esp_light_sleep_start();

  if (err == ESP_ERR_INVALID_STATE){
    ESP_LOGE(TAG,"Trying to sleep: Invalid state error");
  }
  ESP_LOGI(TAG,"AWAKE");
}

void espShutdown(){
  // display.setStatusMessage("LOW BATTERY");
  // ESP_LOGI(TAG,"LOW BATTERY shutting down");
  // esp_deep_sleep_start();
}
#endif

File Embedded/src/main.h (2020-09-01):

#pragma once

#include <Arduino.h>

#include <SPI.h>

#include <Wire.h>
#include <RTClib.h>

// Weather type definitions
#include "weather/weather.h"

#include "network.h"

#if defined(ESP32)
// #define BATTERY_MONITORING
#define BATTERY_PIN A13
#endif

#if defined(CLOCKBRAIN)
#define TOUCH_PIN T7
#define LIGHT_PIN 36
#else
#define TOUCH_PIN T6
#define LIGHT_PIN A2
#endif


// Function declarations

void updateDisplayPreferences();


float currentBrightness();
long detectTouchPeriod();

void sensibleDelay(int milliseconds);

#if defined(BATTERY_MONITORING)
float batteryVoltage();
float batteryLevel(float voltage);

static float cutoffVoltage = 3.3f;
static float maxVoltage = 4.2f;

#if defined(ESP32)
void espSleep(int seconds);
void espShutdown();
#endif

#endif

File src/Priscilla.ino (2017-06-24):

#include <Arduino.h>


#include <SPI.h>
#include <WiFi101.h>
#include <WiFiUdp.h>
#include <Wire.h>
#include <RTClib.h>
#include <RGBDigit.h>
#include <ArduinoJson.h>


// CONFIGURATION  --------------------------------------

// Time zone adjust
int utcAdjust = 1 * 3600;

// Set to false to display time in 12 hour format, or true to use 24 hour:
#define TIME_24_HOUR      true

// Keep track of the hours, minutes, seconds displayed by the clock.
// Start off at 0:00:00 as a signal that the time should be read from
// the DS1307 to initialize it.
int hours = 0;
int minutes = 0;
int seconds = 0;

// Remember if the colon was drawn on the display so it can be blinked
// on and off every second.
bool blinkColon = false;


// ----------- Display

#define DIGIT_COUNT 4
RGBDigit rgbDigit(DIGIT_COUNT, 11);
uint8_t brightness;

// ----------- RTC

// Create display and RTC_DS3231 objects.  These are global variables that
// can be accessed from both the setup and loop function below.

RTC_DS3231 rtc = RTC_DS3231();

// ----------- WIFI

char ssid[] = "***REMOVED***";  //  your network SSID (name)
char pass[] = "***REMOVED***";       // your network password
int keyIndex = 0;            // your network key Index number (needed only for WEP)

// ----------- TIME SERVER

unsigned int localPort = 2390;      // local port to listen for UDP packets

// IPAddress timeServer(130, 88, 202, 49);//ntp2a.mcc.ac.uk
//IPAddress timeServer(129, 6, 15, 28); // time.nist.gov NTP server
//IPAddress timeServer(194,35,252,7); //chronos.csr.net
IPAddress timeServer(129, 250, 35, 251); //some other one from the pool
// char timeServerPool[] = "pool.ntp.org";

const int NTP_PACKET_SIZE = 48; // NTP time stamp is in the first 48 bytes of the message

byte packetBuffer[ NTP_PACKET_SIZE]; //buffer to hold incoming and outgoing packets

// A UDP instance to let us send and receive packets over UDP
WiFiUDP Udp;

// ----------- RANDOM MESSAGES

const char* messages[] = {
  "commit",
  "best nest",
  "aline is a piglet",
  "all your base are belong to us",
  "what time is it",
  "sarah is very nice",
  "do the ham dance",
  "bobbins",
  "sam is really clever",
  "i am not a hoover",
  "i want all the things",
  "i like our new house",
  "i want to be more glitchy",
  "striving to be less shite every nanosecond",
  "it was just a baby fart",
  "sam is a sausage. he should wake up."
};

#define numMessages (sizeof(messages)/sizeof(char *)) //array size

int randoMinute = random(0,59);

// ------------ TYPES

struct Colour {
  uint8_t red;
  uint8_t green;
  uint8_t blue;
};

// ----------- COLOUR
const Colour WHITE = {120,128,128};
const Colour RED = {128, 0, 0};
const Colour ORANGE = {128, 96, 0};
const Colour YELLOW = {96, 96, 0};
const Colour GREEN = {0, 128, 15};
const Colour LIGHT_BLUE = {80, 80, 128};
const Colour BLUE = {0, 40, 128};
const Colour DARK_BLUE = {20, 0, 50};
const Colour GRAY = {64,64,64};
const Colour DARK_GRAY = {32,32,32};
const Colour BROWN = {55,55,30};
const Colour OTHER_BROWN = {40,60,0};

// DEFAULT RAINBOW
const Colour RAINBOW[5] = {
    RED,ORANGE,GREEN,BLUE,WHITE
};

Colour currentColours[5];

// ---------- WEATHER

const char server[] = "datapoint.metoffice.gov.uk";
const char resource[] = "/public/data/val/wxfcs/all/json/351207?res=daily&key=***REMOVED***"; // http resource
const unsigned long HTTP_TIMEOUT = 10000;  // max respone time from server
const size_t MAX_CONTENT_SIZE = 4096;       // max size of the HTTP response
WiFiClient client;

// ---------- WEATHER TYPE COLOUR PATTERNS

const Colour weatherTypeColours[][5] = {
  {DARK_BLUE,DARK_BLUE,DARK_BLUE,DARK_BLUE,DARK_GRAY}, // 0 - clear night
  {YELLOW,YELLOW,YELLOW,YELLOW,WHITE},             // 1 - sunny day
  {DARK_BLUE,DARK_GRAY,DARK_BLUE,DARK_GRAY,DARK_GRAY},           // 2 - Partly cloudy night
  {YELLOW,GRAY,YELLOW,GRAY,WHITE},                 // 3 - Partly cloudy day
  {WHITE,WHITE,WHITE,WHITE,WHITE},                 // 4 - unused
  {WHITE,GRAY,WHITE,GRAY,WHITE},                 // 5 - mist
  {BROWN,BROWN,BROWN,BROWN,WHITE},                 // 6 - fog
  {GRAY,BROWN,GRAY,BROWN,WHITE},                 // 7 - cloudy
  {BROWN,BROWN,BROWN,BROWN,WHITE},                 // 8 - overcast
  {BLUE,DARK_BLUE,BLUE,DARK_BLUE,DARK_GRAY},                 // 9 - light rain shower (night)
  {RED,ORANGE,GREEN,BLUE,WHITE},        // 10 - light rain shower (day)
  {LIGHT_BLUE,LIGHT_BLUE,LIGHT_BLUE,LIGHT_BLUE,WHITE},  // 11 - Drizzle
  {LIGHT_BLUE,LIGHT_BLUE,LIGHT_BLUE,LIGHT_BLUE,WHITE}, // 12 - Light rain
  {DARK_BLUE,BLUE,DARK_BLUE,BLUE,DARK_GRAY}, // 13 - Heavy rain shower (night)
  {YELLOW,BLUE,YELLOW,BLUE,WHITE},// 14 - Heavy rain shower (day)
  {BLUE,BLUE,BLUE,BLUE,WHITE},// 15 - Heavy rain
  {DARK_BLUE,WHITE,DARK_BLUE,WHITE,DARK_GRAY},// 16 - Sleet shower (night)
  {YELLOW,WHITE,YELLOW,WHITE,WHITE},// 17 - Sleet shower (day)
  {WHITE,WHITE,WHITE,WHITE,WHITE},// 18 - Sleet
  {DARK_BLUE,WHITE,DARK_BLUE,WHITE,DARK_GRAY},// 19 - Hail shower (night)
  {YELLOW,WHITE,YELLOW,WHITE,WHITE},// 20 - Hail shower (day)
  {WHITE,WHITE,WHITE,WHITE,WHITE},// 21 - Hail
  {DARK_BLUE,WHITE,DARK_BLUE,WHITE,DARK_GRAY},// 22 - Light snow shower (night)
  {YELLOW,WHITE,YELLOW,WHITE,WHITE},// 23 - Light snow shower (day)
  {WHITE,WHITE,WHITE,WHITE,WHITE},// 24 - Light snow
  {DARK_BLUE,WHITE,DARK_BLUE,WHITE,DARK_GRAY},// 25 - Heavy snow shower (night)
  {WHITE,YELLOW,WHITE,WHITE,WHITE},// 26 - Heavy snow shower (day)
  {WHITE,WHITE,WHITE,WHITE,WHITE},// 27 - Heavy snow
  {DARK_BLUE,ORANGE,BLUE,DARK_BLUE,DARK_GRAY},// 28 - Thunder shower (night)
  {BLUE,DARK_GRAY,BLUE,ORANGE,WHITE},// 29 - Thunder shower (day)
  {DARK_GRAY,BLUE,ORANGE,YELLOW,WHITE},// 30 - Thunder
  {RED,ORANGE,GREEN,BLUE,WHITE}, // 31 - rainbow
};
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

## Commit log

2017-05-04 Fixed leading zeros during first 10 mins of the day
    [Priscilla.ino]
2017-05-04 Removed 1s delay after NTP fail
    [Priscilla.ino]
2017-05-04 Hasty reworking for RGBDigits
    [Priscilla.ino]
2017-05-05 Got rid of the LED 7seg stuff
2017-06-16 Tried to make weather persist if fetch fails
    [Priscilla.ino]
2017-06-24 Got the wrong rtc all this time
    [Priscilla.ino]
2017-06-24 Corrected some abuse of char*
    [Priscilla.ino]
2017-06-26 Brigtness using LDR on pin 0
2017-06-30 Name of feather board in Platformio doesn't have _usb on it any more.
2017-07-03 Frame-centric rather than second-centric
2017-07-11 Swapped delay() calls for FastLed.delay() calls
    [Priscilla.cpp, display.cpp]
2017-07-14 Moved printf style logger into its own file
2018-09-21 Brightness tweaks because the LEDs are dimmer
2019-04-18 Mostly works on ESP32
2019-04-20 Fixed metoffice problems with new arduinojson framework and memory
    [Priscilla.cpp]
2019-06-05 Battery warning
2019-06-14 Removed sublime project (which was all linter settings that didn't really work and anyway vscode)
    [Priscilla.ino]
2019-06-14 Moved some of the low level esp32 rtc experiments out of the main file
2019-06-14 Slight tweaks to ESP32 wifi connection stuff
2019-06-17 Loads of changes - but crashy
    [Priscilla.cpp]
2019-06-29 Whole world of flipflop
    [Priscilla.cpp]
2019-07-10 Changed GPS to 10hz updates
2019-07-12 RGBDigit implementation: Brought back temperature gradients and tidied
2019-08-03 Fixed the esp32 sleep crashing!
    [Priscilla.cpp]
2019-08-05 Show battery level again on epaper
2019-09-12 Daily OTA updates! (#23)
    * Started implementation of firmware updates
    * Parse releases json from github
    * Removed unused includes
    * Semver library and version parsing
    * Firmware updates might work perhaps
    * Firmware updates work and say to wait while happening
    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
2019-09-17 Tweaked temperature gradient colours
2019-09-17 Scaling the heat palette should only happen when the weather changes
2019-10-11 Correct LED type
2019-10-13 Set the no-weather temperatures to zero - which will be white
2019-10-13 Switched back to darksky and pass it location
2019-11-03 Manufacturing data and case colours, lots of other stuff
2019-11-13 Rainbows 🌈 (#28)
    * RAINBOWS ARE BACK
    * Relaxed the rain-chance for rainbow generation
    * Sorted out the temperature gradients
    * fresh messages
    * Slightly reduced odds of rainbows
    * Cleanup and general tinkering
2019-11-18 Print a bunch of stuff to serial on startup
2019-11-21 Rough error state using the dot
    [Priscilla.cpp, RGBDigit.h]
2020-05-11 Correct colour order for matrix
    [Matrix.h]
2020-05-12 Fixed frozen wind speed animation cycles
    [Matrix.h, Priscilla.cpp]
2020-05-15 Swapped some header locking for #pragma once
    [Matrix.h]
2020-05-15 Simplified time fetching from ESP32 rtc so it's non-blocking
2020-05-16 Bumped up ADC sensitivity for ambient light sensor
2020-05-25 The heatwave is actually a wave
2020-05-25 Attempt to figure out touch pin issues on clockbrain
    [Priscilla.cpp]
2020-06-25 Enabled esp32_exception_decoder ZOMG!
2020-06-28 Deployment guide and efuse burning recipe
    [Matrix.h, Priscilla.cpp]
2020-07-07 Added localTime method to the ESP32 RTC wrapper
2020-07-09 Correct light pin for both devices
2020-07-12 Fixed future OTA failure by disabling watchdog timer
    [Priscilla.cpp]
2020-07-16 Disconnect devices on backgrounding and exit
2020-07-17 Added reset buttons and various other layout improvements
2020-07-17 Added ability to reboot and factoryReset from bluetooth
    [Priscilla.cpp]
2020-07-19 Bluetooth advertising - manufacturer data contains hwrev, case colour, serial
2020-07-20 Move the reset and Device Info BT things into BTTechnicalService, Abstract out efuse reading
2020-07-20 Update deployment.md case colour list
2020-07-23 No, don't free the bluetooth device name or you end up with garbage
2020-07-23 Added "configured" property to current location json structure
2020-07-24 Enabled switching of time style (12 hour, 24 hour, decimal) over bluetooth
2020-07-24 Added ability to switch time styles
2020-07-25 Added a shared button style
2020-07-25 Switched back to a viewmodel for networkSummaryView
2020-07-25 Started tightening up some of the internals of CombineBluetooth
2020-07-29 Added gold case colour as number 6
2020-07-29 Added gold case colour
2020-07-29 Hide the not-got-a-clocklet button if you've got a clocklet
2020-07-30 Refactored Preferences Glue with generics of a sort - glue for staging mode
2020-07-30 Added autoUpdates preferences glue
2020-07-31 Disable firmware updates if switched off in preferences
2020-07-31 Moved firmware update switch further down
2020-08-03 SSL and refactored HTTP fetching
    - Implemented HTTPnihClient (not invented here)
    - ssl verification for weather updates
    - refactored firmware updates
    - commented out metoffice code
    commit 2412408a35752444c424d97d750de229b9772114
    Author: Sam Easterby-Smith <me@samscam.co.uk>
    Date: Mon Aug 3 10:15:07 2020 +0100
    Static allocation of nih within weather client
    commit 428f4c0982692ee68f1e1d6bc8e6610504ea0cc2
    Author: Sam Easterby-Smith <me@samscam.co.uk>
    Date: Mon Aug 3 10:13:17 2020 +0100
    Firmware updates using NIH client - but not certs because I can't guarantee that they won't change under me
    commit 40c04ce9f03405609f4f1ab22a2b9a26b8974d3a
    Author: Sam Easterby-Smith <me@samscam.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
    [Priscilla.cpp]
2020-08-04 Switch on notifications within the network service when needed
2020-08-04 Renamed CurrentLocation to ClockLocation
2020-08-06 LocationDetails has some more sample places including ones with funny timezones
2020-08-11 Corrected bluetooth start/stop for feather-based clocklets
    [Priscilla.cpp]
2020-08-16 Added clockbrain board definition (so others can build it!)
2020-08-16 Case insensitive thunder for darksky
2020-08-23 Brightness glue is now a float
2020-08-30 Very small cleanup of firmware update memory capacity
2020-08-30 Auto brightness switch is going in after all
2020-08-31 Added MapKit and CoreLocation into the project frameworks list
2020-09-02 Added nimble-arduino
2020-09-02 Couple of upstream changes
2020-09-03 nimble-arduino v1.0.1
2020-09-04 LocationSource no longer had the isnan definition (prob from arduino lib)
2020-09-04 Touch sensor flag in ini file
2020-09-04 Fix sticky autoBrightness switch
2020-09-08 Refactored Location to ClockLocation to avoid collision with SolTrack
    [Priscilla.cpp]
2020-09-10 iOS - ask for location permission on button press
2020-09-12 Corrected url in the board definition file
2020-09-13 Couple of messages. Some were too long.
2022-09-18 Fixed broken toggle switches and pickers
2022-10-01 Switch statement to handle whether initial setup has been done
2022-10-02 Removed a boilerplate test case
2022-10-07 nimble-arduino to 1.4.0
2022-10-07 Moved nimble-arduino from submodule to platformio dependency
2022-10-07 Fixed glue tags (again)
2022-10-09 Switch current weather client to OWM
2022-12-06 Removed sloppy redirect handling as it’s now done by the library
2022-12-08 iOS: Fancier buttons
2022-12-08 iOS: factory reset button looked stupid
2022-12-16 Embedded: Decided that weather summary is now synopsis and also that it’s broken
    [main.cpp]
2022-12-30 iOS: Some refactoring of Bluetooth Overlay … kinda fixes #47 but still could be better
2023-01-01 Embedded: Firmware updates don’t retry if they fail for a sensible reason (like there is no binary)
2023-01-02 iOS: don’t invalidate BT services or characteristics on disconnect
2023-06-27 Possible wonky targeted device family
2025-04-02 Add a spacer to fix misalignment of NetworkDetails section
2025-04-06 Bunged much electronics design stuff in the repo. It's a mess.
    [Clocklet-board.kicad_pcb, Clocklet-board.kicad_sch, Clocklet-board.sch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]
2025-05-10 Started work on v6 schematic
    [Clocklet-v6.kicad_pcb, Clocklet-v6.kicad_sch, Display.kicad_pcb]
